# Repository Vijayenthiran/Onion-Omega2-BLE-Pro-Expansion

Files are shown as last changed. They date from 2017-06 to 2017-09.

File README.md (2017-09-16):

## Onion Omega 2 BLE Pro Expansion Board

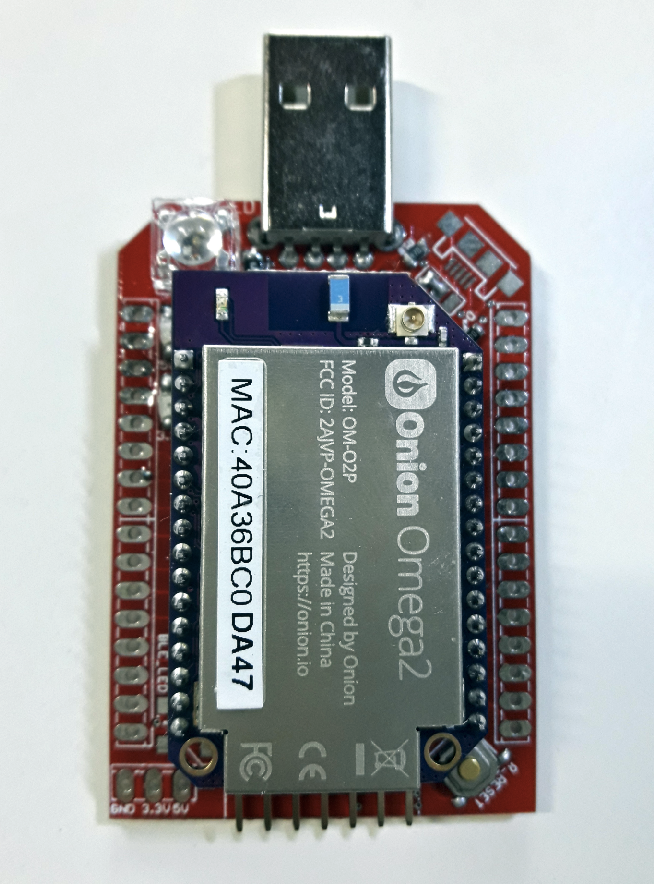
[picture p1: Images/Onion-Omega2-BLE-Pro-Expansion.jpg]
Onion-Omega2-BLE-Pro-Expansion


[Onion Omega 2](https://onion.io/omega2/) is a $5 Linux computer with Wifi support. It is great for developing Internet of Things (IoT) applications. Unfortunately, the board cannot be powered directly as there is no option for USB power. Also, it uses 2 mm pitch headers which makes it impossible to use with a regular breadboard without any converter/expansion board. Even after powering the Omega 2, accessing the terminal should be done through wifi. All these problems make Omega 2 less easy to get started. 

This expansion board addresses the above-mentioned issues with some additional features at a very low cost compared to the expansion boards [available](https://onion.io/product-category/docks/) from Onion Crop directly. 

**Features:**

- Breakout board for Onion Omega 2 (*2.00mm to 2.54mm*).
- Access Onion Omega 2 Terminal without Wifi Connection.
- Adds BLE support to the Omega 2 (*Software support TBD. Contributions welcomed*).
- Standalone BLE device HM-11 (*Throught Serial AT Commands*). 
- Standalone USB to Serial programmer/debugger. 
- Program any Arduino or ESP8266.
- 5V to 3.3V converter (*Up to 700mA*).
- Onboard RGB LED.
- Contains both USB A Male and Micro USB female (*Selectable via jumpers*).

**Getting Started:**
- Install [CH340G driver](https://sparks.gogo.co.nz/ch340.html) *before* plugging into your computer. Restart the computer if required.
- Plug your Onion Omega 2 into the 2.00mm header. Make sure you plug in the correct orientation (Onion Logo should face the USB port).
- Get to know how to access USB Serial devices. Here are some recommended articles: [Windows](https://software.intel.com/en-us/setting-up-serial-terminal-on-system-with-windows) | [Linux](https://stackoverflow.com/a/6719367) | [Mac](https://software.intel.com/en-us/setting-up-serial-terminal-on-system-with-mac-os-x)
- Open the Serial Console and wait for some time (usually 2 to 3 mins) for the Omega 2 to boot up. You will see a lot of messages like this:
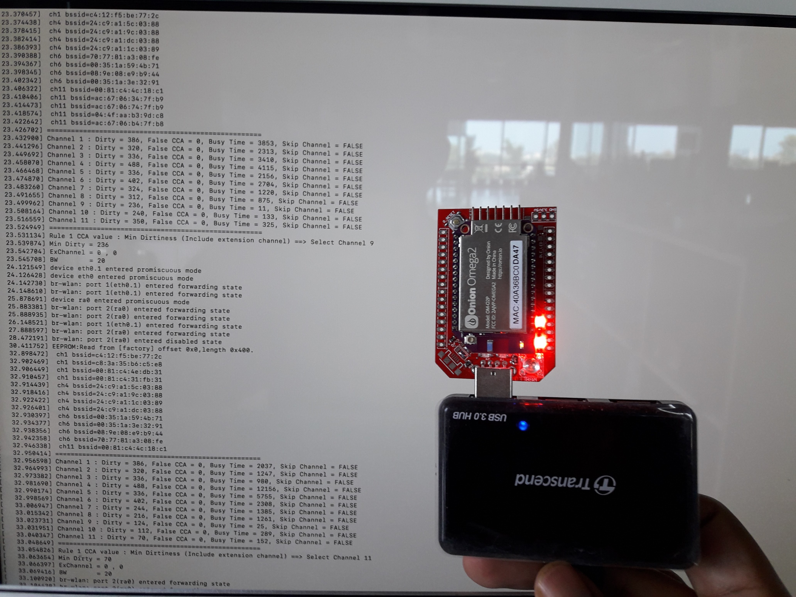
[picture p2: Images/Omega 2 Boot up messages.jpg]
Omega 2 Boot up messages
  
- Press Enter key twice. You are good to go. Head over to [Onion Omega 2 Documentation page](https://docs.onion.io/omega2-docs/connecting-to-the-omega-terminal.html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) for more information. 

**RGB LED demo**:
- Install [python](https://wiki.onion.io/Tutorials/Installing-Python).
- Enter the command `cd root` and press enter.
- Type `vi RGBDemo.py` and press `i` key.
- Copy paste this code:
```
    import onionGpio
    # for delay
    import time

    # Create GPIO object
    gpioObject17 = onionGpio.OnionGpio(17)
    gpioObject16 = onionGpio.OnionGpio(16)
    gpioObject15 = onionGpio.OnionGpio(15)

    time.sleep(0.01)

    status = gpioObject17.setOutputDirection(1)
    status = gpioObject16.setOutputDirection(1)
    status = gpioObject15.setOutputDirection(1)

    while True:
        for r in range(0,2):
            for g in range(0,2):
                for b in range(0,2):
                    status = gpioObject17.setOutputDirection(r)
                    status = gpioObject16.setOutputDirection(g)
                    status = gpioObject15.setOutputDirection(b)
                    time.sleep(0.01)
```
- Press `ESC` key and press `:wq` and press enter. Now your file will be saved.
- Enter the command `python RGBDemo.py` and press enter. You should see your RGB enter changing its color.
- To terminate the demo press `CTRL + C`.

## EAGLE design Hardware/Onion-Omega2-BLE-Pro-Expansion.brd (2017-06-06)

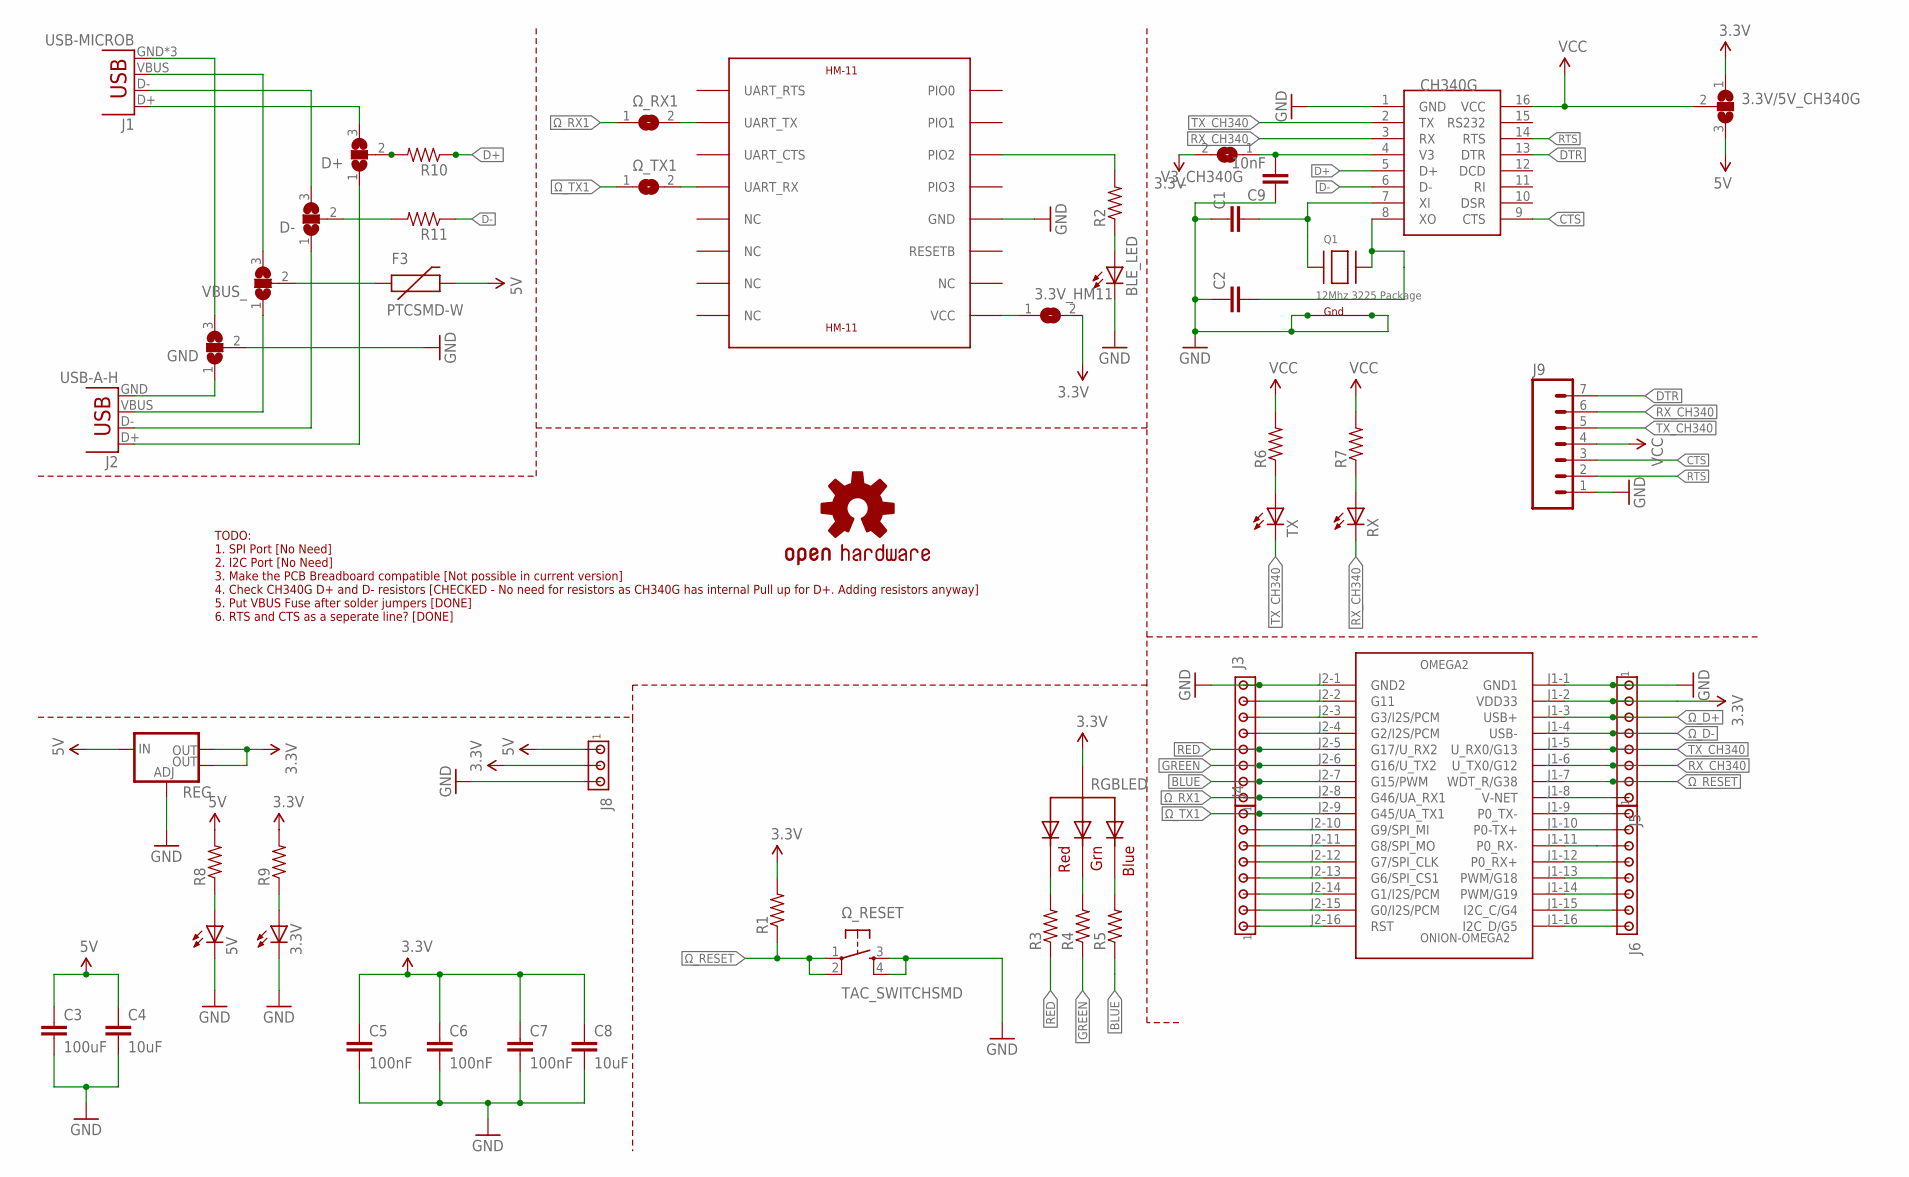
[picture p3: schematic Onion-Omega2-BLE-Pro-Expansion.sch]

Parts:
3.3V, 5V: LEDCHIPLED_1206; CHIPLED_1206
3.3V/5V_CH340G: SJ2W; SJ_2
3.3V_HM11: SJ
BLE_LED: LEDCHIPLED_1206; CHIPLED_1206
C1, C2: CAP1206; 1206
C3: 100uF; 1206
C4, C8: 10uF; 1206
C5, C6, C7: 100nF; 1206
C9: 10nF; 1206
D+: SJ2W; SJ_2
D-: SJ2W; SJ_2
F3: PTCSMD-W; PTC-1206-WIDE
GND: SJ2W; SJ_2
J1: USB-MICROB
J2: USB-A-H
J3, J4, J5, J6: MTA08-100; 10X08MTA
J8: MTA03-100; 10X03MTA
J9: M07SMD; 1X07-SMD-FEMALE-V2
LOGO1: OSHW-LOGOMINI; OSHW-LOGO-MINI
OMEGA2: ONION-OMEGA2; ONION-2MM-2X16
Q1: 12Mhz 3225 Package; NX3225
R1, R2, R3, R4, R5, R6, R7, R8, R9: RESISTOR1206; 1206
R10, R11: RESISTOR0805-RES; 0805
REG: V_REG_LM1117SOT223; SOT223
RGBLED: RGBLED_CA-PIRANHA; PIRANHA5MM
RX: LEDCHIPLED_1206; CHIPLED_1206
TX: LEDCHIPLED_1206; CHIPLED_1206
U$1: CH340G; SOIC16
U$2: HM-11
V3_CH340G: SJ
VBUS_: SJ2W; SJ_2
Ω_RESET: TAC_SWITCHSMD; TACTILE-SWITCH-SMD
Ω_RX1: SJ
Ω_TX1: SJ

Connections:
3.3V: 3.3V/5V_CH340G.1, 3.3V_HM11.2, C5.1, C6.1, C7.1, C8.1, J5.2, J8.2, OMEGA2.J1-2 (VDD33), R1.2, R9.2, REG.2 (OUT), REG.4 (OUT), RGBLED.4 (VCC), V3_CH340G.2
5V: 3.3V/5V_CH340G.3, C3.1, C4.1, F3.2, J8.1, R8.2, REG.3 (IN)
BLUE: J3.2, OMEGA2.J2-7 (G15/PWM), R5.1
CTS: J9.3, U$1.9 (CTS)
D+: R10.1, U$1.5 (D+)
D-: R11.1, U$1.6 (D-)
DTR: J9.7, U$1.13 (DTR)
GND: 3.3V.C, 5V.C, BLE_LED.C, C1.1, C2.1, C3.2, C4.2, C5.2, C6.2, C7.2, C8.2, C9.1, GND.2, J3.8, J5.1, J8.3, J9.1, OMEGA2.J1-1 (GND1), OMEGA2.J2-1 (GND2), Q1.2 (G2), Q1.4 (G1), REG.1 (ADJ), U$1.1 (GND), U$2.GND, Ω_RESET.3, Ω_RESET.4
GREEN: J3.3, OMEGA2.J2-6 (G16/U_TX2), R4.1
unnamed: C1.2, Q1.1 (X1), U$1.7 (XI)
unnamed: C2.2, Q1.3 (X2), U$1.8 (XO)
unnamed: R2.2, U$2.PIO2
unnamed: BLE_LED.A, R2.1
unnamed: U$2.UART_TX, Ω_RX1.2
unnamed: J3.7, OMEGA2.J2-2 (G11)
unnamed: J3.6, OMEGA2.J2-3 (G3/I2S/PCM)
unnamed: J3.5, OMEGA2.J2-4 (G2/I2S/PCM)
unnamed: C9.2, U$1.4 (V3), V3_CH340G.1
unnamed: R6.1, TX.A
unnamed: U$2.UART_RX, Ω_TX1.2
unnamed: 3.3V_HM11.1, U$2.VCC
unnamed: J4.7, OMEGA2.J2-10 (G9/SPI_MI)
unnamed: J4.6, OMEGA2.J2-11 (G8/SPI_MO)
unnamed: J4.5, OMEGA2.J2-12 (G7/SPI_CLK)
unnamed: J4.4, OMEGA2.J2-13 (G6/SPI_CS1)
unnamed: J4.3, OMEGA2.J2-14 (G1/I2S/PCM)
unnamed: J4.2, OMEGA2.J2-15 (G0/I2S/PCM)
unnamed: J4.1, OMEGA2.J2-16 (RST)
unnamed: R3.2, RGBLED.2 (RED)
unnamed: R4.2, RGBLED.3 (GREEN)
unnamed: R5.2, RGBLED.1 (BLUE)
unnamed: R7.1, RX.A
unnamed: 5V.A, R8.1
unnamed: 3.3V.A, R9.1
unnamed: F3.1, VBUS_.2
unnamed: J5.8, OMEGA2.J1-8 (V-NET)
unnamed: J6.1, OMEGA2.J1-9 (P0_TX-)
unnamed: J6.2, OMEGA2.J1-10 (P0-TX+)
unnamed: J6.3, OMEGA2.J1-11 (P0_RX-)
unnamed: J6.4, OMEGA2.J1-12 (P0_RX+)
unnamed: J6.5, OMEGA2.J1-13 (PWM/G18)
unnamed: J6.6, OMEGA2.J1-14 (PWM/G19)
unnamed: J6.7, OMEGA2.J1-15 (I2C_C/G4)
unnamed: J6.8, OMEGA2.J1-16 (I2C_D/G5)
unnamed: J2.VBUS, VBUS_.1
unnamed: D+.2, R10.2
unnamed: GND.1, J2.GND
unnamed: GND.3, J1.GND, J1.MT1 (GND), J1.MT2 (GND)
unnamed: J1.VBUS, VBUS_.3
unnamed: D-.3, J1.D-
unnamed: D+.3, J1.D+
unnamed: D-.2, R11.2
unnamed: D-.1, J2.D-
unnamed: D+.1, J2.D+
RED: J3.4, OMEGA2.J2-5 (G17/U_RX2), R3.1
RTS: J9.2, U$1.14 (RTS)
RX_CH340: J5.6, J9.6, OMEGA2.J1-6 (U_TX0/G12), RX.C, U$1.3 (RX)
TX_CH340: J5.5, J9.5, OMEGA2.J1-5 (U_RX0/G13), TX.C, U$1.2 (TX)
VCC: 3.3V/5V_CH340G.2, J9.4, R6.2, R7.2, U$1.16 (VCC)
Ω_D+: J5.3, OMEGA2.J1-3 (USB+)
Ω_D-: J5.4, OMEGA2.J1-4 (USB-)
Ω_RESET: J5.7, OMEGA2.J1-7 (WDT_R/G38), R1.1, Ω_RESET.1, Ω_RESET.2
Ω_RX1: J3.1, OMEGA2.J2-8 (G46/UA_RX1), Ω_RX1.1
Ω_TX1: J4.8, OMEGA2.J2-9 (G45/UA_TX1), Ω_TX1.1

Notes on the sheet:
TODO: 1. SPI Port [No Need] 2. I2C Port [No Need] 3. Make the PCB Breadboard compatible [Not possible in current version] 4. Check CH340G D+ and D- resistors [CHECKED - No need for resistors as CH340G has internal Pull up for D+. Adding resistors anyway] 5. Put VBUS Fuse after solder jumpers [DONE]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

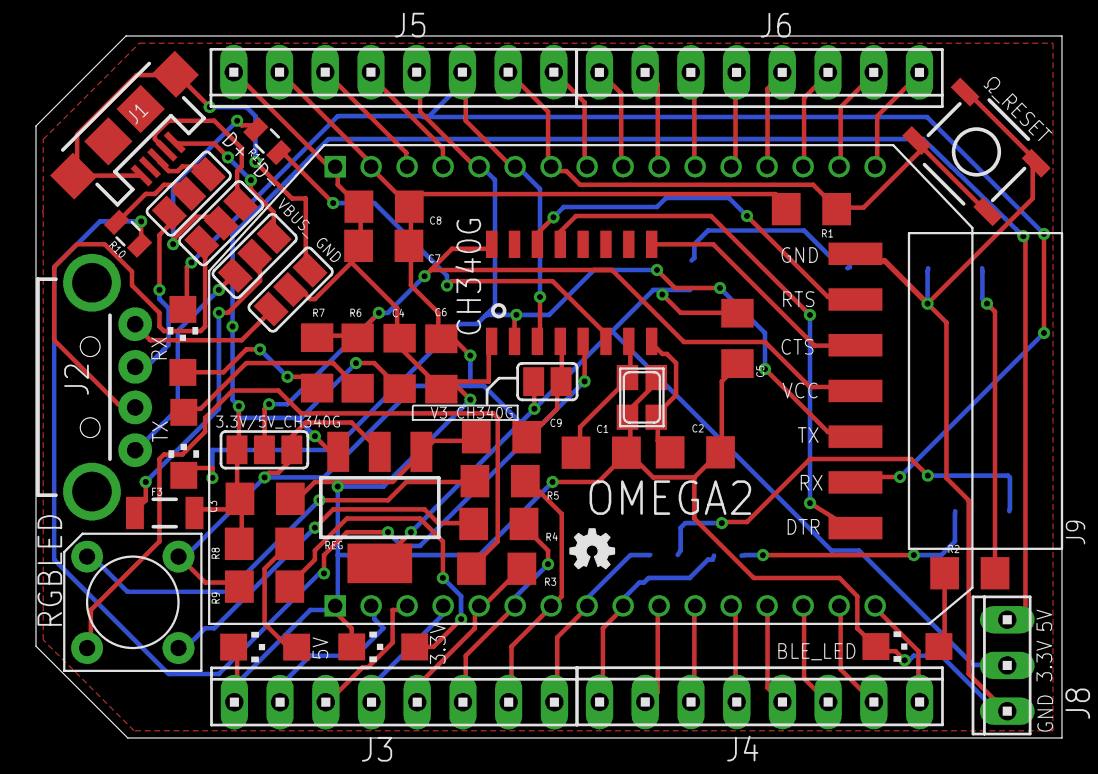
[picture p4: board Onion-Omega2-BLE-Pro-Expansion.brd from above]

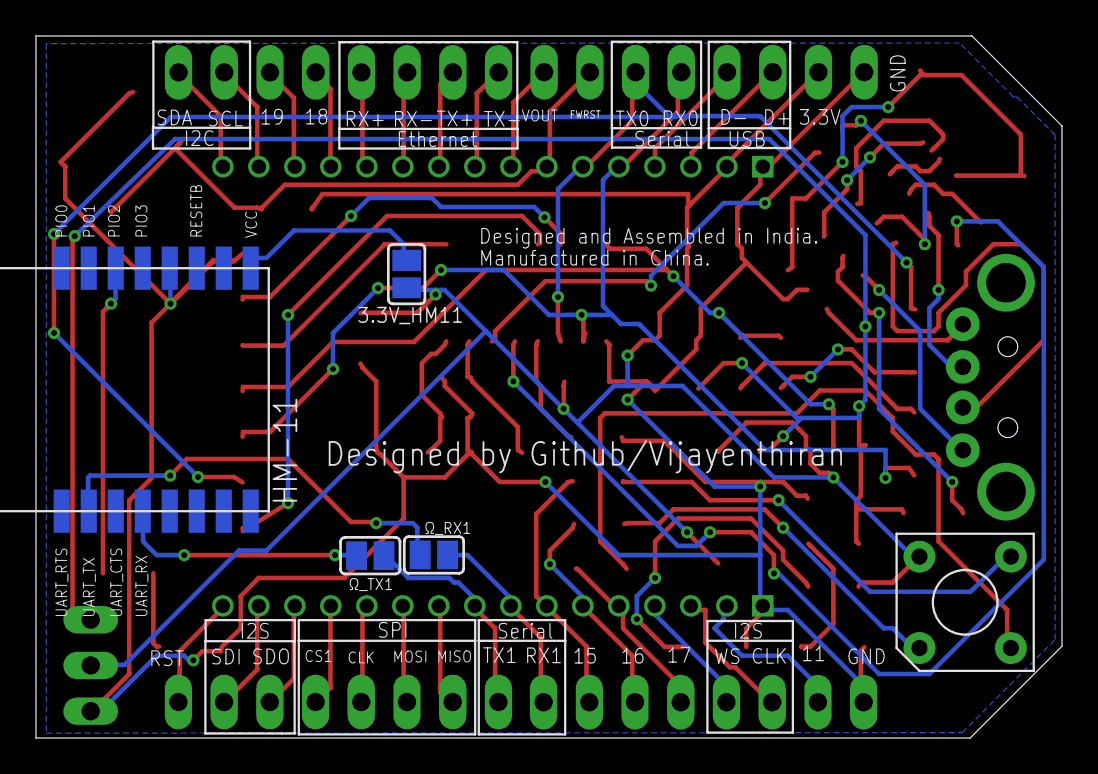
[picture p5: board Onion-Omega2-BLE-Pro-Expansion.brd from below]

Board: 2 copper layers, 57.0 x 39.0 mm, 51 parts (4 on the bottom side), 64 nets.

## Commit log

2017-05-01 Fixed symlink
    [Onion-Omega2-BLE-Pro-Expansion.brd, Onion-Omega2-BLE-Pro-Expansion.sch]
2017-05-01 Board Size reduced. Replaced almost all PTH with SMD. CH340G breakout. Minor improvements. Halfway manual routing. Lots of DRC errors
    [Onion-Omega2-BLE-Pro-Expansion.brd, Onion-Omega2-BLE-Pro-Expansion.sch]
2017-05-02 Routing done with the help of autorouter. Not satisfied with few components placements
    [Onion-Omega2-BLE-Pro-Expansion.brd, Onion-Omega2-BLE-Pro-Expansion.sch]
2017-05-02 v0.1 freeze. Placements looks good.
    [Onion-Omega2-BLE-Pro-Expansion.brd, Onion-Omega2-BLE-Pro-Expansion.sch]
2017-05-24 Silk Screen Fix
    [Onion-Omega2-BLE-Pro-Expansion.brd, Onion-Omega2-BLE-Pro-Expansion.sch]
2017-05-26 VBUS fused moved after jumper. Resistors for D+ and D- Lines. TODO: Reduce D+ line length
    [Onion-Omega2-BLE-Pro-Expansion.brd, Onion-Omega2-BLE-Pro-Expansion.sch]
2017-06-06 CTS and RTS lines seperated. Sent for production
    [Onion-Omega2-BLE-Pro-Expansion.brd, Onion-Omega2-BLE-Pro-Expansion.sch]

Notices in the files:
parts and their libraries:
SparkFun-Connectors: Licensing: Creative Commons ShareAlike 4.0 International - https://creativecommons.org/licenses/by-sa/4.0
